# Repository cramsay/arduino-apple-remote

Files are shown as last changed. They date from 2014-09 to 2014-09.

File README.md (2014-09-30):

arduino-apple-remote
========================

A low power arduino sketch to imitate an apple remote.

A big thanks to Shirriff for his breakdown of atmegea328 PWM
and his [Arduino-IRremote](https://github.com/shirriff/Arduino-IRremote) remote.
My IR code is essentially a stripped down version of his, with a few minor modifications.

## Setup Instructions

1. Burn the bootloader for the "Arduino Uno with 1.8V BOD" (if running at ~3 V from batteries)
2. Upload sketch to MCU
3. Construct hardware as shown in schematic

If you have another atmega328, you can use the [ArduinoISP](http://arduino.cc/en/Tutorial/ArduinoISP)
sketch to burn the bootloader without a separate programmer.

## Hardware

The setup is based on an atmega328 MCU.  
An IR LED is connected to arduino pin 3.  
There are 6 buttons (missing the play/pause button introduced in the newer remotes) connected
to arduino pins 7 through 12.
The internal atmega328 pullup resistors are used for the button signals.  
To wake the MCU up from the POWER_DOWN sleep mode, I use an external interrupt.
The interrupt signal is all of the button signals ANDed together using a 4082 IC.

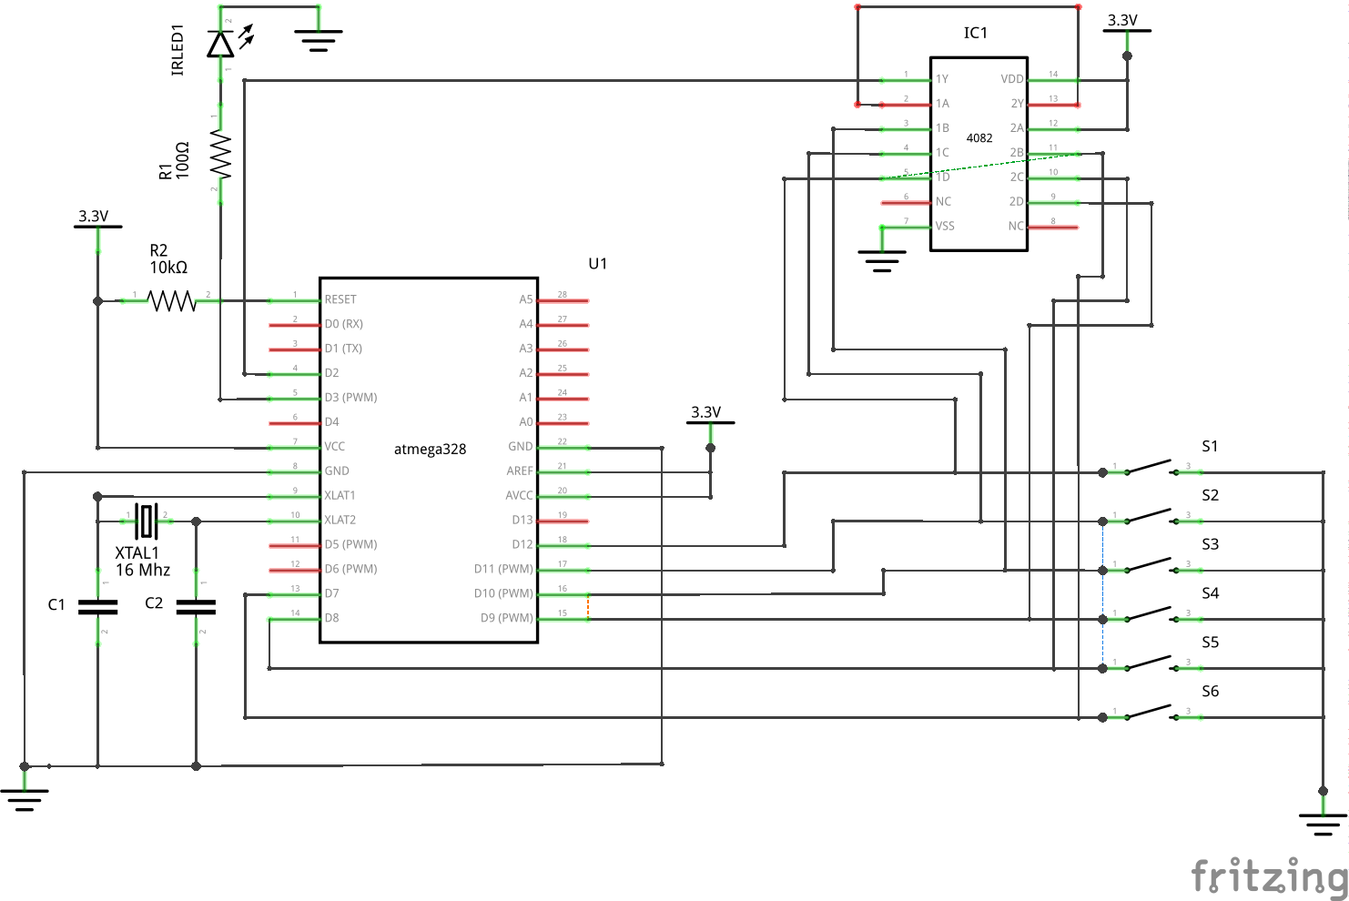
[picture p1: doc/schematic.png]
Schematic Diagram


## Brown Out Detection (BOD)

I'm running the MCU on a 3V coin cell battery and by default the arduino bootloader sets fuse
bits to have a 2.7 V BOD limit. Because of this, I ran into brown out issues as the battery discharged.
To combat this, I made a custom entry in my boards.txt file with the fuse bits for a 1.8 V BOD limit.

## Power Saving

There are a few components on the arduino uno board which inevitably draw a fair bit of current.
Because of this, I moved my design to a minimal atmega328 circuit powered by batteries with _no_
voltage regulator. Further power savings were gained by disabling I2C, SPI, ADC, and USART0 via the 
power reduction register (PRR) in the setup function. Also you can disable BOD during sleep using the
`sleep_bod_disable()` function. Here are a few measurements I took along the way...

Description                    | Sleep   | Active
-------------------------------|---------|--------
Arduino Uno (5V)               | 26.2 mA | 43.0 mA
Atmega328 (5V)                 | 0.29 mA | 12.55 mA
/wo I2C, SPI, ADC, and USART0  | 17 uA   | 6.5 mA
with BOD disabled during sleep | 0.1 uA  | 6.5 mA

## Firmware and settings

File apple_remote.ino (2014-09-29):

/**
 * @file apple_remote.ino
 * @author Craig Ramsay
 * @date 29 Sep 2014
 * @brief Replacement arduino based apple remote control
 */

#include "ir_remote.h"
#include <avr/interrupt.h>
#include <avr/power.h>
#include <avr/sleep.h>

//Button state
typedef enum {off,debounce,on} btn_state_e;
typedef struct
{
    btn_state_e state;
    int pin;
} btn_state_t;
btn_state_t btns[] = {{off,7},{off,8},{off,9},{off,10},{off,11},{off,12}};
#define NUM_BTNS sizeof(btns)/sizeof(btn_state_t)

//Cmd codes
#define CMD_BYT_UP 0x0B
#define CMD_BYT_DOWN 0x0D
#define CMD_BYT_LEFT 0x08
#define CMD_BYT_RIGHT 0x07
#define CMD_BYT_CENTRE 0x04
#define CMD_BYT_MENU 0x02
byte cmd_bytes[] = {CMD_BYT_UP,CMD_BYT_LEFT,CMD_BYT_RIGHT,
					CMD_BYT_DOWN,CMD_BYT_CENTRE,CMD_BYT_MENU};

//Sleep stuff
//#define NO_SLEEP

/**
Setup routine run once at power on

Disables various unused features for power savings.
Sets up button connections with internal pullup resistors
*/
void setup()
{
    //Turn off I2C, SPI, ADC, USART0
    ADCSRA = 0;
    PRR = B10010111;

    //Setup btn pins (input with internal pullup enabled)
    for(int i=0; i<NUM_BTNS; i++) {
        pinMode(btns[i].pin,INPUT);
        digitalWrite(btns[i].pin,HIGH);
    }
}

/**
Reset all recorded button states to "off"
*/
void clear_btn_state() {
    for(int i=0; i<NUM_BTNS; i++) {
        btns[i].state=off;
    }

}

/**
Check all current button states and dispatch IR commands

Each active button is promoted to "debounce" state then
"on" on the next call. Whenever a button is promoted to
"on", the corresponding IR command is sent.
*/
void check_btns() {
    //For each button
    for(int i=0; i<NUM_BTNS; i++) {
        //If btn is pressed
        if(digitalRead(btns[i].pin)==0) {

            //Promote debouncing btns to pressed
            if(btns[i].state==debounce) {
                btns[i].state=on;
                //Send button command
                send_ir_cmd(cmd_bytes[i]);
            }
            //Promote off btns to "just pressed"
            else if(btns[i].state==off)
                btns[i].state=debounce;

            //Set to "not pressed"
        } else {
            btns[i].state=off;
        }
    }
}

/**
Sends the MCU to sleep safely

The MCU is set to the PWR_DOWN sleep mode.
An interrupt will wake the MCU when any button is depressed.
*/
void sleepNow(void)
{
#ifdef NO_SLEEP
    return;
#endif

    // Allow sleeping (disabled on interrupt)
    sleep_enable();
    set_sleep_mode(SLEEP_MODE_PWR_DOWN);

    // Set pin 2 as interrupt and attach handler:
    attachInterrupt(0, pinInterrupt, LOW);

	// Disable brown out detection when sleeping
	sleep_bod_disable();

    // Sleep
    sleep_cpu();

    // Code continutes from here once woken up
    sleep_disable();
}

/**
Simple interrupt on pin 2 to wake up the MCU from sleep mode
*/
void pinInterrupt(void)
{
    detachInterrupt(0);
    //Stop the MCU going into sleep if this is triggered too early
    sleep_disable();
}

/**
Main control loop

When no buttons are active sleep mode is triggered.
Otherwise, buttons are checked as normal.
*/
void loop() {
    //If no buttons are pressed, go to sleep (infer from interrupt signal)
    if(digitalRead(2)) {
        sleepNow();
        clear_btn_state();
    }
    //Check buttons at least twice due to debouncing code
    check_btns();
    delay(25);
    check_btns();
    delay(25);
}

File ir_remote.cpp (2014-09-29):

#include "ir_remote.h"

#include "Arduino.h"
#include <avr/interrupt.h>

/**
 * Sends an IR mark for the given number of microseconds.
 * The mark output is modulated at the PWM frequency 
 *
 * @param time Microsecond duration of the mark
 */
void mark(int time) {
  TIMER_ENABLE_PWM;
  delayMicroseconds(time);
}

/**
 * Sends an IR space for the specified number of microseconds.
 * A space is no output, so the PWM output is disabled.
 *
 * @param time Microsecond duration of the space
 */
void space(int time) {
  TIMER_DISABLE_PWM;
  delayMicroseconds(time);
}

/**
 * Enable IR PWM controls at a given modulation frequency
 *
 * TIMER2 is used in phase-correct PWM mode, with OCR2A controlling the frequency and OCR2B
 * controlling the duty cycle.
 * There is no prescaling, so the output frequency is 16MHz / (2 * OCR2A)
 * To turn the output on and off, we leave the PWM running, but connect and disconnect the output pin.
 * A few hours staring at the ATmega documentation and this will all make sense.
 * See post "Secrets of Arduino PWM" at http://arcfn.com/2009/07/secrets-of-arduino-pwm.html for details.
 *
 * @param khz The desired modulation frequency
 */
void enable_ir_out(int khz) {

  pinMode(TIMER_PWM_PIN, OUTPUT);
  digitalWrite(TIMER_PWM_PIN, LOW); // When not sending PWM, we want it low
  
  // COM2A = 00: disconnect OC2A
  // COM2B = 00: disconnect OC2B; to send signal set to 10: OC2B non-inverted
  // WGM2 = 101: phase-correct PWM with OCRA as top
  // CS2 = 000: no prescaling
  // The top value for the timer.  The modulation frequency will be SYSCLOCK / 2 / OCR2A.
  TIMER_CONFIG_KHZ(khz);
}

/**
Sends a single IR NEC command

It uses the Arduino-IRremote library to do the clever PWM stuff.
Builds the whole payload (apple uid : cmd : remote id) and then
sends the bytes in order, but least significant bit first.
See https://en.wikipedia.org/wiki/Apple_Remote#Technical_details
for details on the cmd codes and parity bit.

@param cmd_code the command code to be sent
*/
void send_ir_cmd(unsigned char cmd_code)
{
    byte data[] = {0xEE,0x87,cmd_code,0x59};

    enable_ir_out(38);

    //Send AGC leader
    mark(NEC_HDR_MARK);
    space(NEC_HDR_SPACE);

    //Send each byte in order, but least sig bit first
    for (int i = 0; i < sizeof(data)/sizeof(byte); i++) {
        for(int j=0; j<8; j++) {
            if (data[i] & 1) {
                mark(NEC_BIT_MARK);
                space(NEC_ONE_SPACE);
            }
            else {
                mark(NEC_BIT_MARK);
                space(NEC_ZERO_SPACE);
            }
            data[i] >>= 1;
        }
    }
    mark(NEC_BIT_MARK);
    space(0);
}

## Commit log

2014-09-27 Added button controls and basic sleep mode
2014-09-27 Fixed some interrupt/wake timing bugs
    [apple_remote.ino]
2014-09-28 Focused on more power saving
2014-09-29 Sleep on button release
2014-09-29 Added schematic
    [schematic.fzz]
2014-09-29 Broke out IRremote library to only have what is needed
    [apple_remote.ino, ir_remote.cpp, ir_remote.h]
2014-09-29 Fixed lib conversion and disabled BOD when sleeping
    [apple_remote.ino, ir_remote.h]
